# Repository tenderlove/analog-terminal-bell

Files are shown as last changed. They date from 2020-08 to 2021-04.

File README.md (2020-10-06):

# Analog Terminal Bell

Welcome to the Analog Terminal Bell!

The Analog Terminal Bell is a bell that rings any time a bell character is
displayed on your terminal.  Simply plug the bell in to USB and enable "Analog
Bell" in your terminal settings.

Never miss a terminal bell notification again!

Here is a photo of the bell:

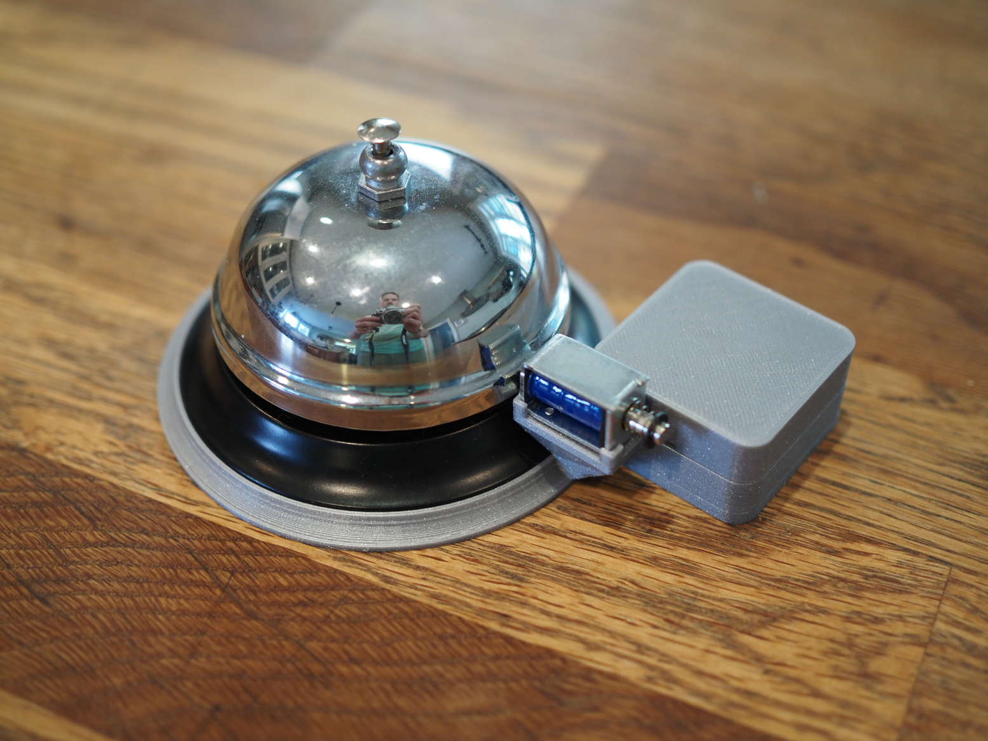
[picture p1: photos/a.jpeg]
Analog Terminal Bell Photo


Here is a video explanation:

Analog Terminal Bell (https://www.youtube.com/watch?v=uG8VpN6Z_YA)

## Actual Product Details

This bell is not actually for sale.  You have to build it yourself!  This
project uses an MCP2221A microchip to drive a solenoid and hit a bell.

### Electronic Hardware

Information about the electronic hardware to build this project can be found in
the `pcb` folder.  Just check out the [README](pcb/README.md) there for details
on how to build the electronic hardware for this project.

I used through hole components on the PCB to make assembly as easy as possible.

### Physical Hardware

The bell can be found at many stores like [amazon](https://www.amzn.com/s?k=bell) or [staples](https://www.staples.com/call+bell/directory_call%2520bell)

### Software

Unlike an Arduino, this microchip doesn't need any firmware, we can control it
via USB HID.  See the [README](software/README.md) in the `software` folder for
details on how to control the bell from your computer.

Note that if you want iTerm2 to ring the bell like in the commercial, you'll
need a custom build of iTerm2.  You can find the patches for iTerm2
[here](https://github.com/tenderlove/iTerm2/tree/analog-terminal-bell).

### Case and Mounting

The case is 3D printed and the stl files can be found in the [case](case) folder.

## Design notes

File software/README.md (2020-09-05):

# Analog Terminal Bell Software

The Analog Terminal Bell uses the GPIO pin of an MCP2221a to fire a solenoid
and hit the bell.  This is all done over USB.

## Configuring the Analog Terminal Bell

By default, the MCP2221a doesn't use GP0 as a general purpose IO, so we need to
configure it before using it.  This only needs to be done once, ever.  I use a
Ruby library called "UChip" to do the initial configuration:

```ruby
require "uchip/mcp2221"

# This example changes the "startup" GPIO settings of the chip.

# Find the first connected chip
chip = UChip::MCP2221.first || raise("Couldn't find the chip!")

# Get the GPIO settings
settings = chip.gp_settings

settings.gp0_designation = 0   # We want to use this pin as a GPIO
settings.gp0_output_value = 0  # Set the default value to 0
settings.gp0_direction = 0     # Set the direction to output

# Write the settings to the chip.  Next time the chip starts, the default
# settings for GP0 will reflect these settings
chip.gp_settings = settings
```

## Controlling the Analog Terminal Bell

The Analog Terminal Bell can be controlled with Circuit Python, but I don't
know how.  I've been testing it with a Ruby library called "UChip".  To install
the gem, just do `gem install uchip`.

Here is the code to control the bell with Ruby:

```ruby
require "uchip/mcp2221"

def hit_bell pin
  pin.value = 0
  pin.value = 1
  sleep 0.009
  pin.value = 0
end

# Find the first connected chip
chip = UChip::MCP2221.first || raise("Couldn't find the chip!")

pin = chip.pin 0
pin.output!

loop do
  hit_bell pin
  sleep 2
end
```

## Analog Terminal Bell and iTerm2

Currently the Analog Terminal Bell requires a custom build of iTerm2 to work.
Building from [this
branch](https://github.com/tenderlove/iTerm2/tree/analog-terminal-bell) will
enable the Analog Terminal Bell feature in iTerm2.

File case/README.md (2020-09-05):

# Analog Terminal Bell Case

This case was designed with OpenSCAD, but I've checked in the STL files so you
can just print them directly!

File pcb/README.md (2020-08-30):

# Analog Terminal Bell PCB

This directory contains the PCB design for the analog terminal bell.

## PCB

The PCB is designed using KiCad.  If you don't want to deal with KiCad, it's no
problem.  Just upload the `gerbers.zip` file to any PCB manufacturer and you
should be on your way!

## Components

Here are the components needed:

* [Mini USB B Connector](https://www.digikey.com/product-detail/en/molex/0548190519/WM17115-ND/773802) ($1.72)
* [10k resistor](https://www.digikey.com/product-detail/en/stackpole-electronics-inc/CF14JT10K0/CF14JT10K0CT-ND/1830374) ($0.10)
* [1k resistor](https://www.digikey.com/product-detail/en/stackpole-electronics-inc/CF14JT1K00/CF14JT1K00CT-ND/1830350) ($0.10)
* [47nf capacitor](https://www.digikey.com/product-detail/en/vishay-beyschlag-draloric-bc-components/K473K15X7RF5TH5/BC1099CT-ND/286721) ($0.22)
* [1N4004 diode](https://www.digikey.com/product-detail/en/micro-commercial-co/1N4004-TP/1N4004-TPMSCT-ND/773691) ($0.12)
* [TIP 122 or 102](https://www.digikey.com/product-detail/en/stmicroelectronics/TIP102/497-2546-5-ND/603571) ($0.70)
* [Solenoid](https://www.digikey.com/product-detail/en/sparkfun-electronics/ROB-11015/1568-1592-ND/6163694) ($4.95)
* [MCP2221a](https://www.digikey.com/product-detail/en/microchip-technology/MCP2221A-I-P/MCP2221A-I-P-ND/6009296) ($2.27)
* [JST connector](https://www.digikey.com/short/zfj702) ($0.17)
* [14 Pin Socket](https://www.digikey.com/product-detail/en/on-shore-technology-inc/ED14DT/ED3045-5-ND/4147595) ($0.18)

* [Bell](https://www.amazon.com/gp/product/B07816SJSB/) ($7.99)

The electronic components for this project should cost around $11 (before
shipping, taxes, etc).

## Assembly

All of the components go on top of the board, except the USB connector. The
USB connector goes on the bottom of the board!

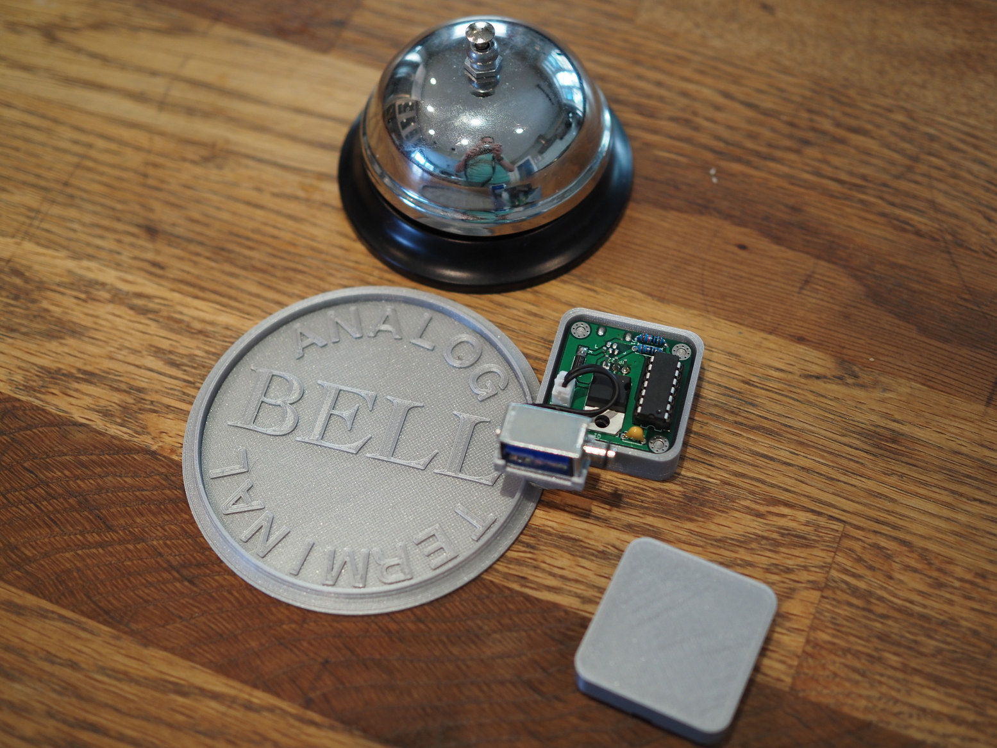
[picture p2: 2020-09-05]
photos/c.jpeg

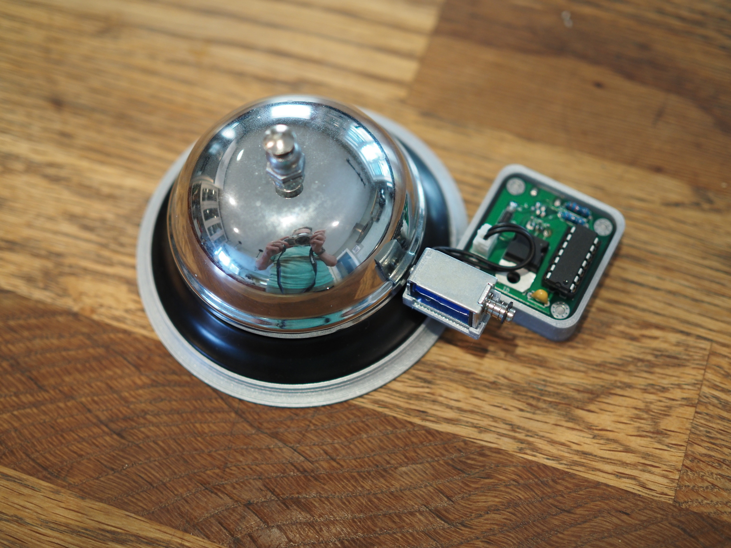
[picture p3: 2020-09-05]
photos/b.jpeg

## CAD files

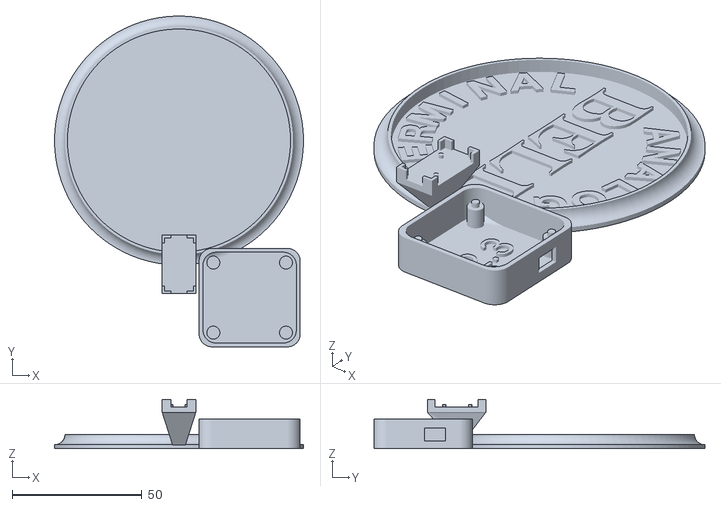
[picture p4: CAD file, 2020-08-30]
case/case.stl
96.0 x 127.5 x 19.0

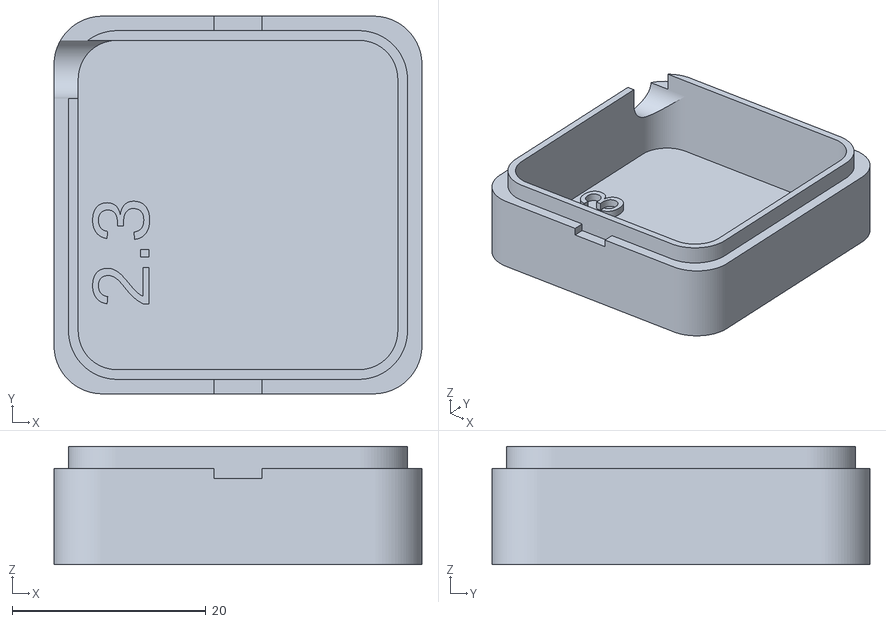
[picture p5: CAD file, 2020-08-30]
case/lid.stl
38.0 x 39.0 x 12.2

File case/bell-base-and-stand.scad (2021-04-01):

use <solenoid-stand.scad>
use <solenoid-mount.scad>
use <pcb.scad>
use <bell-base.scad>

module BellAndSolenoidStand(pcb = true) {
  plate_thickness = 1.5;
  bell_bottom_diameter = 86;
  bell_bottom_radius = bell_bottom_diameter / 2;
  bell_diameter = 70;
  bell_radius = bell_diameter / 2;

  fillet_height = 4;
  bottom_ridge_x = fillet_height + 1;
  to_bell_z = 16.5;
  bell_ridge_z = 6;
  solenoid_x = 11;
  solenoid_y = 20.5;
  solenoid_mount_wall_thickness = 1;

  outer_radius = bell_bottom_radius + bottom_ridge_x;

  max_overhang = bell_bottom_radius - bell_radius;
  distance_from_bell_to_solenoid_case = 2.5;
  overhang = max_overhang - distance_from_bell_to_solenoid_case;


  // align the center of the bell ridge with the center of the solenoid
  // solenoid_mounting_z should be the bottom of the solenoid
  post_bottom_y = ((solenoid_y / 2) - (bell_bottom_radius - bell_radius)) + 1;

  BellBase(plate_thickness, bell_bottom_diameter, fillet_height);

  translate([0, (-(bell_bottom_radius + (solenoid_y / 2))) + overhang, plate_thickness]) {
    solenoid_z = 12;

    post_bottom_thickness = fillet_height + 1;
    center_of_bell_ridge_z = to_bell_z + (bell_ridge_z / 2);
    solenoid_mounting_z = center_of_bell_ridge_z - (solenoid_z / 2);

    echo(outer_radius);
    SolenoidStand(solenoid_mounting_z - solenoid_mount_wall_thickness, overhang + solenoid_mount_wall_thickness, bottom_ridge_x, outer_radius);
    translate([0, 0, solenoid_mounting_z - solenoid_mount_wall_thickness])
      SolenoidMount();
  }

  if (pcb) {
    translate([((34 + 2 + plate_thickness + solenoid_x + 2) / 2) + 2, -(bell_bottom_radius + ((33 + 2 + plate_thickness) / 2)) + 0.7, 0])
      rotate(90)
      PCBCase(plate_thickness, plate_thickness, 6);
  }
}

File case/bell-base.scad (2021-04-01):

module OuterText(txt, r, size=10, font) {
  angle = 180 * size / (PI * r);
  for (i = [0:len(txt) - 1]) {
    rotate([0, 0, -(i + 0.5) * angle])
    translate([0, r])
    text(txt[i], size=size, halign="center", valign="baseline", font=font);
  }
}

module BaseText(plate_thickness, bell_bottom_radius) {
f1 = "Helvetica Neue:style=Bold";
f = "Cochin:style=Bold";

translate([0, 0, plate_thickness]) {
  linear_extrude(1) {
    rotate(325)
      OuterText(txt = "ANALOG", r = (bell_bottom_radius - 12), font = f1);

    rotate(165)
      OuterText(txt = "TERMINAL", r = (bell_bottom_radius - 12), font = f1);
  }
}

rotate(270) {
  translate([0, 4, plate_thickness]) {
    linear_extrude(1) {
      text("BELL", font = f, halign = "center", valign = "center", size = 20);
    }
  }
}
}

module BellBase(plate_thickness, bell_bottom_diameter, fillet_height) {
  bell_bottom_radius = bell_bottom_diameter / 2;
  bottom_ridge_x = fillet_height + 1;

  translate([0, 0, plate_thickness]) {
    color("Violet")
      translate([0, 0, -plate_thickness])
      linear_extrude(height = plate_thickness)
      circle(d = bell_bottom_diameter + (2 * bottom_ridge_x));

    color("Olive")
      rotate_extrude()
      translate([bell_bottom_radius, 0, 0]) {
        union() {
          square(size = [1, fillet_height]);
          translate([1, 0, 0]) {
            intersection() {
              square(fillet_height * 2);
              difference() {
                square(fillet_height * 2, center=true);
                translate([fillet_height, fillet_height]) circle(fillet_height);
              }
            }
          }
        }
      }
  }
  BaseText(plate_thickness, bell_bottom_radius);
}

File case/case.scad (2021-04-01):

$fn = 90;

use <bell-base-and-stand.scad>

BellAndSolenoidStand();

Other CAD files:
case/pcb.scad
case/solenoid-mount.scad
case/solenoid-stand.scad

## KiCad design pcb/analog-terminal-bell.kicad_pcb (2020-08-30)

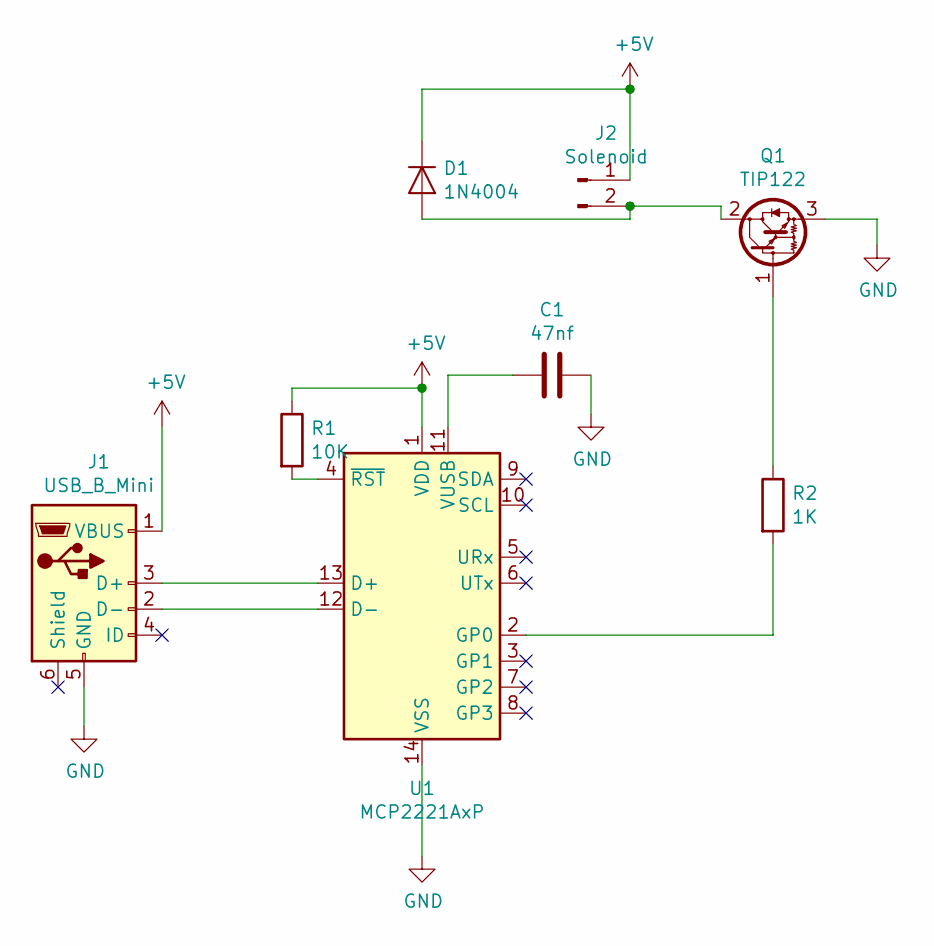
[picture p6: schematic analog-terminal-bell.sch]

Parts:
C1: 47nf; C_Disc_D4.7mm_W2.5mm_P5.00mm
D1: 1N4004; D_DO-41_SOD81_P10.16mm_Horizontal
J1: USB_B_Mini; USB_Mini_B_Female_548190519
J2: Solenoid; JST_PH_B2B-PH-K_1x02_P2.00mm_Vertical
Q1: TIP122; TO-220-3_Horizontal_TabDown
R1: 10K; R_Axial_DIN0207_L6.3mm_D2.5mm_P7.62mm_Horizontal
R2: 1K; R_Axial_DIN0207_L6.3mm_D2.5mm_P7.62mm_Horizontal
U1: MCP2221AxP; DIP-14_W7.62mm

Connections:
+5V: D1.1 (K), J1.1 (VBUS), J2.1, R1.1, U1.1 (VDD)
GND: C1.1, J1.5 (GND), Q1.3 (E), U1.14 (VSS)
unnamed: C1.2, U1.11 (VUSB)
unnamed: D1.2 (A), J2.2, Q1.2 (C)
unnamed: J1.2 (D-), U1.12 (D-)
unnamed: J1.3 (D+), U1.13 (D+)
unnamed: Q1.1 (B), R2.1
unnamed: R1.2, U1.4 (~RST)
unnamed: R2.2, U1.2 (GP0)

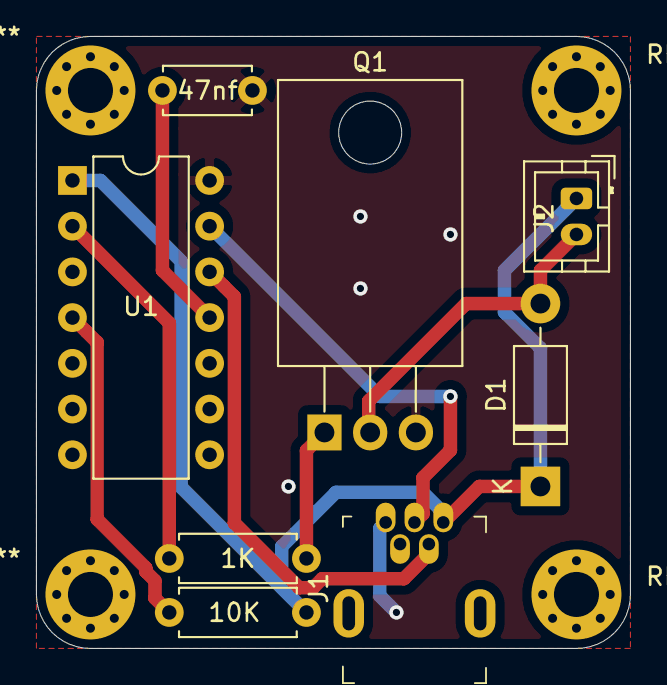
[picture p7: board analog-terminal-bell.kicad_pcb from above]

Board: 2 copper layers, 33.0 x 34.0 mm, 8 parts (0 on the bottom side), 9 nets.

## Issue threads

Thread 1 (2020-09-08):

Video Link Is Broken

puskuruk, 2020-09-08:
I watched the video from Twitter(It was so good😂) but the YouTube link in the README is broken. 🤫

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

tenderlove, 2020-09-08:
Oops!!! Thanks, I'll fix it now.  I guess this is how "product" launches go

tenderlove, 2020-09-08:
Fixed!

Closed 2020-09-08.

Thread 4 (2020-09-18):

Alternate iterm interfaces

kbrock, 2020-09-18:
Instead of using a custom build, iTerm2 suggests that you can use their [python](https://www.iterm2.com/python-api/)

Was your thought to use circuit python and that api to control the bell?

Would be nice to not have to extend iTerm

tenderlove, 2020-09-18:
I don't think the bell was previously available via the Python API, but they made it available here: https://github.com/tenderlove/analog-terminal-bell/issues/4

I think it's possible via the nightly build now so we don't need to have a custom iTerm2 build anymore.

kbrock, 2020-09-22:
ok, so iterm has the ability to kick off a script if it matches a regular expression

that may be another viable solution

tenderlove, 2020-09-23:
oh geez, I linked to the wrong thing.  I don't think we need to do any regexes.  Upstream added the ability for us to detect the bell in a python script here: https://github.com/gnachman/iTerm2/pull/428#issuecomment-691627221

I'll try to hook it up at some point, but the script I linked to just need to have Circuit Python integrated in and it should work.

kbrock, 2020-12-08:
Hey you -- Mr. Tender Love Making,

Thanks for making dumb projects like this.

Tender
>  a person who looks after someone else or a machine or place: Alexei signaled to one of the engine tenders.
> -- apple tender3 example 3

Love
> a great interest and pleasure in something
> -- apple example 2

Making
> ... technology based DIY... revels in the creating of new devices... supports open source... (read the whole paragraph)
> -- https://en.wikipedia.org/wiki/Maker_culture

kbrock, 2020-12-08:
>  I don't think we need to do any regexes

phew. Because regexes and yea. regexes. https://xkcd.com/1171/

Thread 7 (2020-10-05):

Solenoid doesn't fit in case

larsbrinkhoff, 2020-10-05:
Maybe my 3D printer isn't top notch (UltiMaker 2), but I couldn't get the solenoid to fit.

I solved it by setting the GPIO output high, making the soleniod warm enough that it would soften the PLA and I could then force it down.

tenderlove, 2020-10-06:
Huh, did you use the same solenoid from the parts list?  I wonder if they changed the ones they're selling? 😬

larsbrinkhoff, 2020-10-06:
Yes, I ordered everything straight from your official parts list.  Could well be variations in supplier or something.

Anyway, no big deal.  Just FYI.

Closed 2020-10-06.

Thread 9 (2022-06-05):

Alternative parts for discontinued ones

nerdinand, 2022-06-05:
Ohai!

I'm trying to build this and it seems some of the parts listed are discontinued. In particular these 2:

https://www.digikey.ch/en/products/detail/onsemi/TIP102/605466
https://www.digikey.ch/short/zfj702

I have very little knowledge about electronics and was hoping someone could tell me whether these alternatives I found are suitable:

https://www.digikey.ch/en/products/detail/stmicroelectronics/BD241C/2827178
https://www.digikey.ch/en/products/detail/sullins-connector-solutions/SWR201-NRTN-S02-SA-WH/2769600

Thanks for your help!

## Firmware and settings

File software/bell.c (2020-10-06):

#include <stdio.h>
#include <stdlib.h>
#include <unistd.h>
#include <string.h>
#include <hidapi/hidapi.h>

#define VID_MICROCHIP 0x04d8
#define PID_MCP2200 0x00dd

/* Complain and exit. */
static void die (const char *message)
{
  fprintf (stderr, "Error: %s\n", message);
  exit (1);
}

/* Do the HID command/responce dance, with error checking. */
static void hid (hid_device *device, unsigned char *buf)
{
  unsigned char cmd = buf[0];
  int n;

  /* Write data to device. */
  n = hid_write (device, buf, 64);
  if (n != 64)
    die ("hid: write");

  /* Get response from device. */
  memset (buf, 0, 64);
  n = hid_read (device, buf, 64);
  if (n != 64)
    die ("hid: read");
  if (buf[0] != cmd)
    die ("hid: wrong response");
  if (buf[1] != 0x00)
    die ("hid: error code");
}

/* Set GPIO configuration.  Writes to flash. */
static void configure (hid_device *device, int pin)
{
  unsigned char settings[64];

  memset (settings, 0, 64);
  settings[0] = 0xB1; //Write flash data.
  settings[1] = 0x01; //Write GP settings.
  settings[2 + pin] = 0x00; //GP<pin> = GPIO, output, low.
  hid (device, settings);

  memset (settings, 0, 64);
  settings[0] = 0x60; //Set SRAM settings.
  settings[7] = 0x01; //Alter GP designation.
  settings[8 + pin] = 0x00; //GP<pin> = GPIO, output, low.
  hid (device, settings);
}

/* Set GPIO output value. */
static void frob (hid_device *device, int pin, int value)
{
  unsigned char data[64];

  memset (data, 0, 64);
  data[0] = 0x50; //Set GPIO output values.
  data[4 * pin + 2] = 0x01;
  data[4 * pin + 3] = value;
  hid (device, data);
}

/* Make GPIO go high for a specified time. */
static void pulse (hid_device *device, int microseconds)
{
  frob (device, 0, 1);
  usleep (microseconds);
  frob (device, 0, 0);
}

int main (void)
{
  hid_device *device;

  hid_init ();
  device = hid_open (VID_MICROCHIP, PID_MCP2200, NULL);
  if (device == NULL)
    die ("open");

  configure (device, 0);
  frob (device, 0, 0);

  for (;;) {
    pulse (device, 10000);
    sleep (1);
  }
}

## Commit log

2020-08-16 base seems to be working
    [case.scad]
2020-08-21 current version
    [case.scad]
2020-08-22 Adding a solenoid mount design
    [solenoid-mount.scad]
2020-08-22 Make the solenoid mount file `use`able
    [solenoid-mount.scad]
2020-08-22 built the solenoid stand
    [solenoid-stand.scad]
2020-08-22 small refactor
    [solenoid-mount.scad]
2020-08-23 Make post go up
    [solenoid-stand.scad]
2020-08-23 This case seems to work well!
    [case.scad, solenoid-stand.scad]
2020-08-30 update bottom text
    [case.scad]
2020-08-30 seems to be working
    [case.scad, solenoid-stand.scad]
2020-08-30 adding pcb
    [analog-terminal-bell.kicad_pcb, analog-terminal-bell.sch]
2020-08-30 cleaning up case
    [case.scad]
2020-08-30 adding stl files for the case
    [case.stl, lid.stl, pcb.scad]
2020-08-30 more updates
    [analog-terminal-bell.kicad_pcb]
2020-10-04 Sample C program using the cross-platform HIDAPI library.
2021-04-01 refactor case
    [bell-base-and-stand.scad, bell-base.scad, case.scad]
